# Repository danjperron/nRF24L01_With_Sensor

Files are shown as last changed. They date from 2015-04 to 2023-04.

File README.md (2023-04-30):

# nRF24L01_With_Sensor
Read DHT22, DS18B20, MAX6675, Humidity capacitive sensor via nRF24L01 transmitter with an arduino 

Arduino pin out for DHT22

  <pre>
  2   DHT22     DATA with a 4k7 pull-up resistor
  4   DHT22     POWER  I use IO pin to reduce power
  GND DHT22     GND
  3   nRF24L01  IRQ   pin 8.
  7   nRF24L01  CS    pin 4
  8   nRF24L01  CE pin 3
  11  nRF24L01  MOSI  pin 6
  12  nRF24L01  MISO  pin 7
  13  nRF24L01  SCK   pin 5
  3.3V nRF24L01 VCC   pin 2
  GND nRF24L01  GND p in 1
</pre>

N.B. Pins are specific to the sensor.

Needed library 
 - RF24 by TMRh20 from arduino library
 - Sleep_n0m1 by Noah Shibley from arduino library

Needed library for specific sensors
 <s>- http://playground.arduino.cc//Main/DHTLib</s> Check for DHTlib  in library manager
 - http://www.pjrc.com/teensy/td_libs_OneWire.html
<s>- http://milesburton.com/Dallas_Temperature_Control_Library</s>
- https://github.com/milesburton/Arduino-Temperature-Control-Library

And for nRF24Reader.py
 - https://github.com/BLavery/lib_nrf24.git
*** please add SPI clock speed in the function begin if the nRf24L01 doesn't work
    self.spidev.max_speed_hz=8000000

I made some video in French explaining the use of it in my garden
  - Part 1 https://www.youtube.com/watch?v=X7y6lOSt4_s
  - Part 2 https://www.youtube.com/watch?v=79MHdWFCXho
  - Part 3 Not done yet! Will be about humidity calibration and node red

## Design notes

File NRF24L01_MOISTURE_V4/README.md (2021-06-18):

# nRF24L01_With_Sensor
Lire humidité par un capteur capacitif 

Arduino pin out 

  <pre>
  GND Batterie, capteur  GND
  7   nRF24L01  CS    pin 4
  8   nRF24L01  CE pin 3
  11  nRF24L01  MOSI  pin 6
  12  nRF24L01  MISO  pin 7
  13  nRF24L01  SCK   pin 5
  3.3V nRF24L01 VCC   pin 2
  GND nRF24L01  GND p in 1
  9   Capteur CLOCK OUT
  A0  capteur signal
  A1  input foure-tout (pas utilis&acute; mais le systeme retourne la valeur)
</pre>

Librairie nécessaire extraite directement d'arduino 
 - RF24 de TMRh20 
 - Sleep_n0m1 de Noah Shibley 

Librairie Python pour le Raspberry Pi 

 - https://github.com/BLavery/lib_nrf24.git
   *** Il faut corriger la fonction begin pour include la vitesse d`horloge du SPI, sinon c'est trop vite.
    self.spidev.max_speed_hz=8000000
   P.S. une version corrigé du lib_nrf24.git est inclus.
 - numpy      sudo pip3 install numpy  (cela va prendre du temps).
 - mosquitto-clients   sudo pip3 install mosquitto-clients
 
 Si vous n'avez pas de serveur MQTT  vous pouvez en installer un sur le PI
   sudo apt install mosquitto

Information sur les répertoires,

- Demo1    Démo  Transférer du texte.
- Demo2    Démo  Transférer des données en packet.
- Demo3    Démo  Transférer des données en packet mais avec le capteur
           capacitif modifié avec le clock de l`arduino et aussi mettre
           le système en mode sleep.

-RF24L01_MOISTURE_V4  Version final incluant le mode du Demo3 mais en shockburst ce qui permet de synchroniser
           et d'avoir plusieur capteurs.

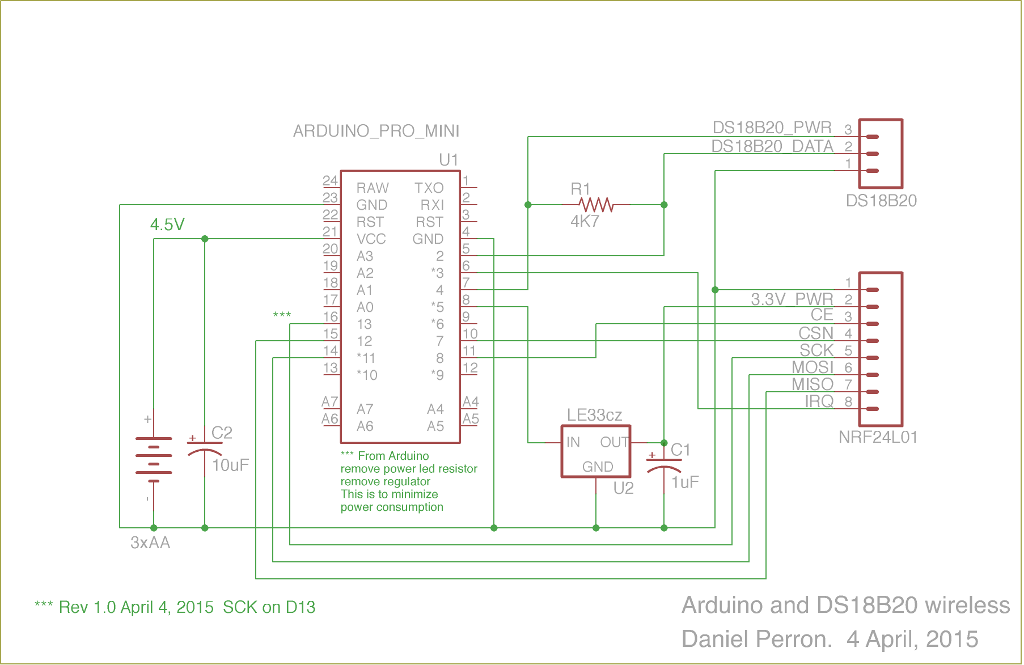
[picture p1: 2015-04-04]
nRF24L01_DS18B20.png

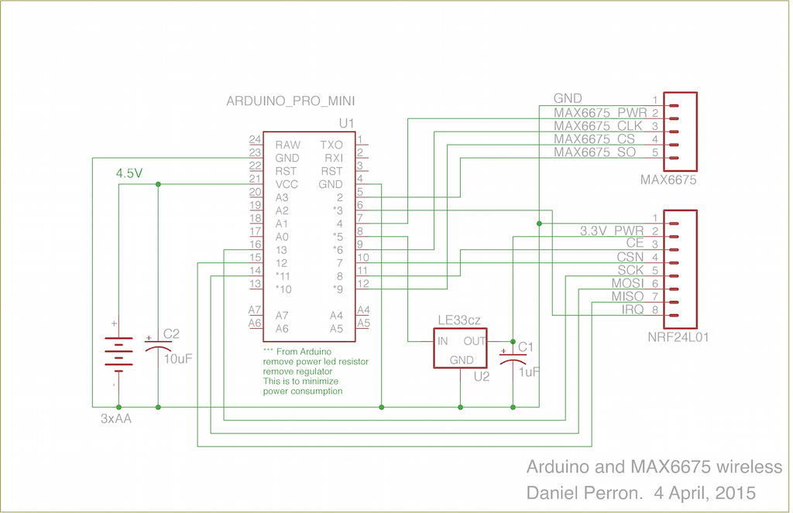
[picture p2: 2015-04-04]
nRF24L01_MAX6675.png

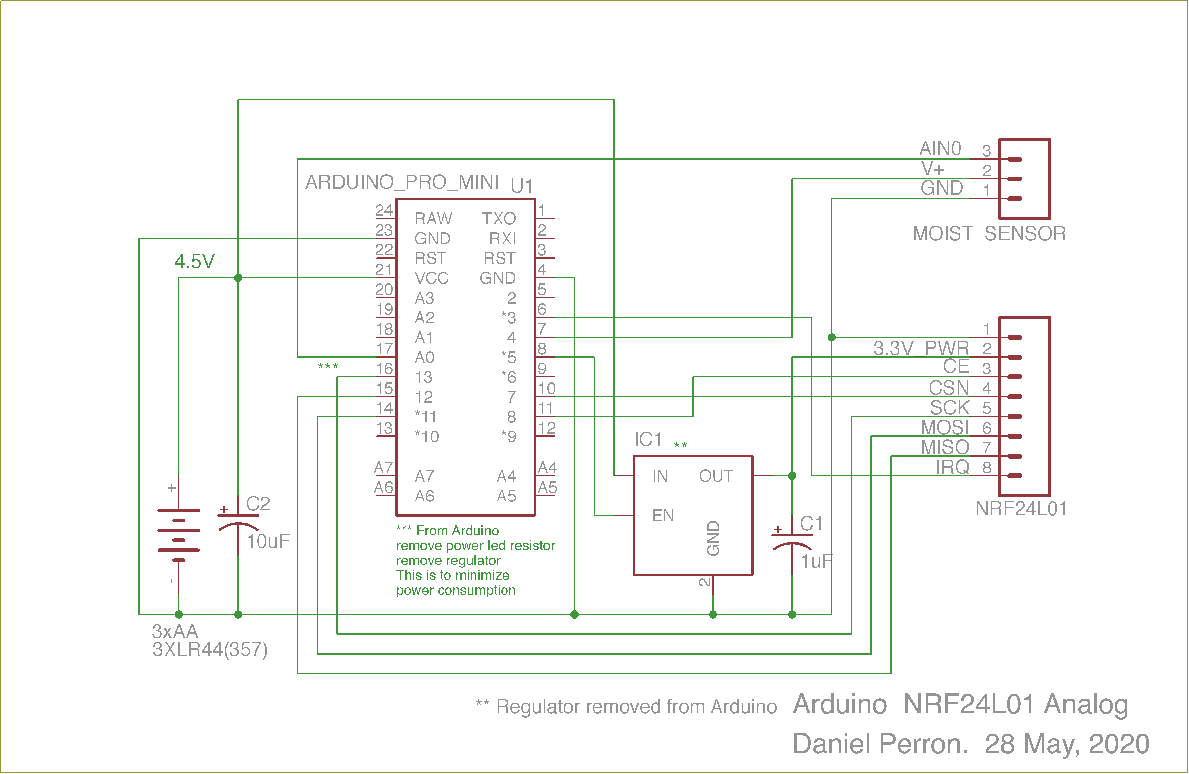
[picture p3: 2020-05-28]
AnalogBeta/nRF24L01_Analog.png

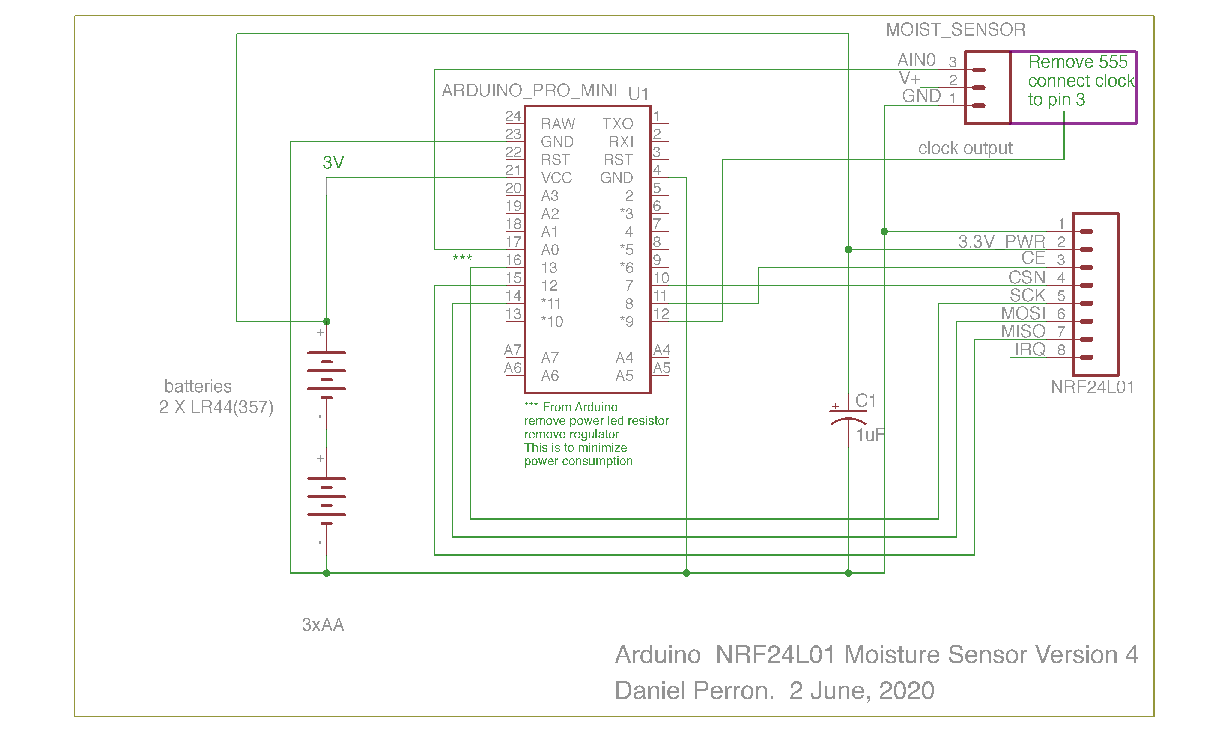
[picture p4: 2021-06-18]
NRF24L01_MOISTURE_V4/RF24L01_MOISTURE_V4.png

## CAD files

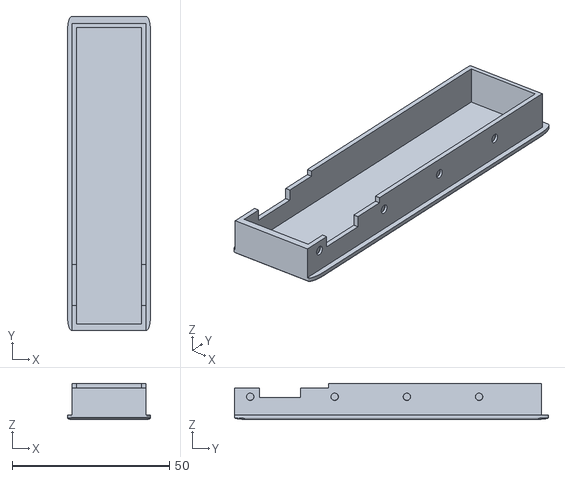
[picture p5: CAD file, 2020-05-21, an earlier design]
NRF24L01_MOISTURE_V2/moisture sensor RF top cover.stl
26.5 x 100.0 x 11.5

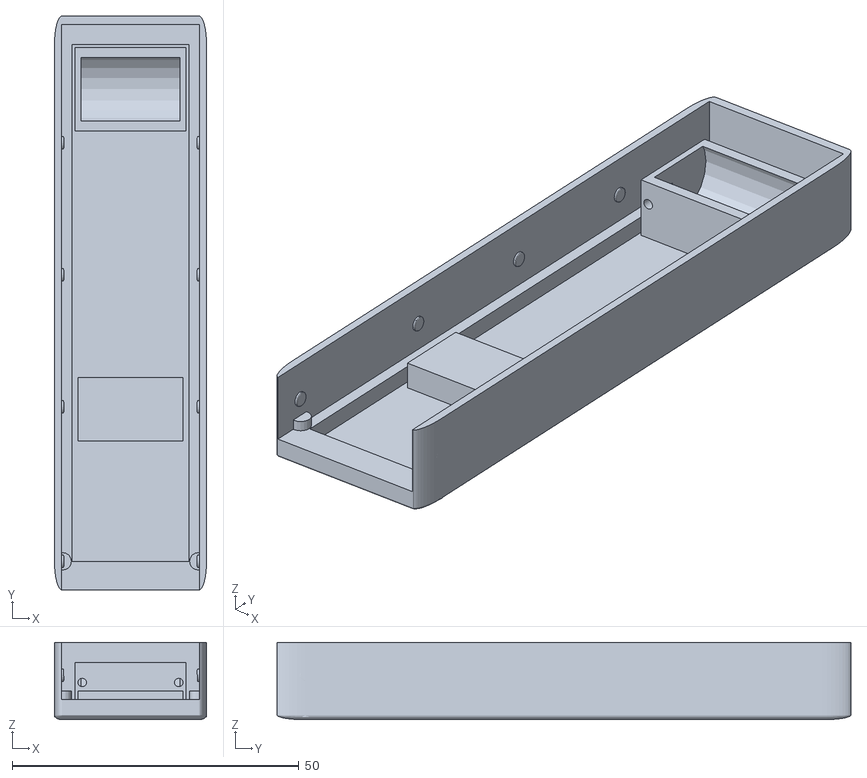
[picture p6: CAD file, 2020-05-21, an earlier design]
NRF24L01_MOISTURE_V2/moisture base cover sensor RF.stl
26.5 x 100.0 x 13.5

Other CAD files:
NRF24L01_MOISTURE_V2/moisture sensor RF box top cover.stl
NRF24L01_MOISTURE_V2/moisture sensor RF box base.stl

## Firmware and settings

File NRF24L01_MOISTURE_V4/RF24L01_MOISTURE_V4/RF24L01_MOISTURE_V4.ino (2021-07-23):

#include <nRF24L01.h>
#include <RF24_config.h>
#include <RF24.h>
#include <SPI.h>
#include <Sleep_n0m1.h>
#include "printf.h"


/*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
  Read Moisture sensor  via nRF24L01 transmitter.

  Version 4.0 June 2021 Daniel Perron

  This is a simplified version using only 3V.
 
  The capacitive sensor has the 555 timer removed and D9 clock the sensor
  
*/



/**** cycle loop behavior *****/

// NO_WAIT    the unit keep looping without doing sleep
//#define NO_WAIT 

// DISABLE_SLEEP    disable deep sleep  use delay instead
//#define DISABLE_SLEEP

#define   SERIAL_DEBUG


/***** capacitive sensor clock definition ****/

#define CLOCK_PIN  9
#define CLOCK_FREQUENCY 800000



/*******  RF24 definition                *****/

// UNIT_ID     ID number of the device for nRF24L01

#define RF24_CE_PIN  8
#define RF24_CSN_PIN 7

//#define RF24_DATA_RATE RF24_1MBPS
//#define RF24_DATA_RATE RF24_2MBPS
#define RF24_DATA_RATE RF24_250KBPS

//#define RADIO_CHANNEL 72
#define RADIO_CHANNEL 80


#define RF24_PA_LEVEL RF24_PA_MIN
//#define RF24_PA_LEVEL RF24_PA_LOW
//#define RF24_PA_LEVEL RF24_PA_HIGH


#define UNIT_ID 0x03

// Radio pipe addresses for the 2 nodes to communicate.
const uint64_t serverPipe = 0xE0E0E0E001LL;
const uint64_t sensorPipe = 0xA5A5A5A500LL | UNIT_ID;


/********   Variables   ******/
short analog0;  // analog capacitive value
short analog1;  // spare analog input
short vcc;      // value of vcc
unsigned long clockFrequency= CLOCK_FREQUENCY;

/*******  sleep mode class ******/
Sleep sleep;
unsigned long sleepTime = 300000;

/******* radio class ******/
RF24 radio(RF24_CE_PIN,RF24_CSN_PIN);

unsigned long Count = 0;

// because of sleep mode calibration problem
// and I don't want to change the library
// we will mimic the calibration
// by disable it and enable only when we reach 0 at modulus 720
// we will calibrate the watch dog  when we wait  for the DS18B20 conversion

#define        WD_CALIB_COUNT   720
unsigned short WDCalibrationCycle = 0;


void StartRadio()
{
#ifdef SERILAL_DEBUG
  Serial.print("*** START RADIO ***\n");
#endif

  radio.begin();                          // Start up the radio
  radio.setChannel(RADIO_CHANNEL);
  radio.setDataRate(RF24_DATA_RATE);
  radio.setPALevel(RF24_PA_LEVEL);
  radio.setPayloadSize(32);
  radio.setAutoAck(1);                    // Ensure autoACK is enabled
  radio.setRetries(7, 4);  // Max delay between retries & number of retries
  radio.enableDynamicPayloads();
  radio.enableAckPayload();
  radio.maskIRQ(true, true, false);
  //role = role_ping_out;                  // Become the primary transmitter (ping out)
  radio.openWritingPipe(serverPipe);
  radio.openReadingPipe(1,sensorPipe);
  radio.startListening();                 // Start listening
}


//***************  TIMER1  CLOCK OSCILLATOR ON OC1A


// clock is on D9
// this only works for frequency CPU_CLOCK/2 to CPU_CLOCK/65536
// adapted to take care of compile cpu clock (F_CPU)
void setClock(unsigned long tempfreq){
  unsigned long SquareWaveClock = (unsigned long) F_CPU /2L;
  pinMode(CLOCK_PIN, OUTPUT);
  cli();//disable interupts
  TCCR1A = 0;//registers for timer 1
  TCCR1B = 0;
  TCNT1=0;
  TCCR1A |= _BV(COM1A0);
  TCCR1B |=_BV(WGM12);
  TCCR1C = _BV(FOC1A);
  OCR1A = (SquareWaveClock/tempfreq)-1;//#TIMER COUNTS
  TCCR1B |= _BV(CS10);
  sei();//enable interupts
}



void killClock(void)
{
  cli();//disable interupts
  TCCR1A = 0;//registers for timer 1
  TCCR1B = 0;
  TCNT1=0;
  sei();
  digitalWrite(CLOCK_PIN,LOW);
}


//****************  800KHZ CLock END



void setup() {
#ifdef SERIAL_DEBUG
  Serial.begin(57600);
  printf_begin();
  printf("\n\rRF24 ANALOG\n\r");
#endif
  StartRadio();
#ifdef SERIAL_DEBUG
  radio.stopListening();
  radio.printDetails();                   // Dump the configuration of the rf unit for debugging
  radio.startListening();
#endif
  // disable calibration interval by setting modulus to
  sleep.setCalibrationInterval(1);

}


/********  cycle state definition *****/

enum cycleMode {ModeInit, ModeListen, ModeReadSensor, ModeWriteData, ModeWait};

cycleMode cycle = ModeInit;



/********  type of sensor definition *****/

#define STRUCT_TYPE_GETDATA    0
#define STRUCT_TYPE_INIT_DATA  1
#define STRUCT_TYPE_DHT22_DATA 2
#define STRUCT_TYPE_DS18B20_DATA 3
#define STRUCT_TYPE_MAX6675_DATA 4
#define STRUCT_TYPE_DIGITAL_OUTPUT 5
#define STRUCT_TYPE_ANALOG_DATA  6
#define STRUCT_TYPE_MOISTURE_DATA 7

#define STATUS_DATA_VALID  1
#define STATUS_TIME_OUT    2


/******* data structure for STRUCT_TYPE_MOISTURE_DATA ******/


typedef struct
{
  char header;
  unsigned char structSize;
  unsigned char structType;
  unsigned char txmUnitId;
  unsigned long currentTime;
  unsigned short nextTimeReading;
  unsigned short nextTimeOnTimeOut;
  unsigned long  clockFrequency;
  unsigned char  clockFrequencyValid;
  char Spare[15];
} RcvPacketStruct;


typedef struct
{
  char header;
  unsigned char structSize;
  unsigned char structType;
  unsigned char txmUnitId;
  unsigned char Status;
  unsigned long  stampTime;
  unsigned short voltageA2D;
  unsigned short analog0;
  unsigned short analog1;
  unsigned long  frequency;
} TxmMoisturePacketStruct;


unsigned long currentDelay;
unsigned long targetDelay;

RcvPacketStruct RcvData;
TxmMoisturePacketStruct Txmdata;

unsigned char * pt = (unsigned char *) &RcvData;


unsigned char rcvBuffer[32];
unsigned short nextTimeOnTimeOut = 300;
const unsigned short waitTimeOnListen = 10;
unsigned long  startTimeOnListen;

void PrintHex(uint8_t *data, uint8_t length) // prints 16-bit data in hex with leading zeroes
{
#ifdef SERIAL_DEBUG
  char tmp[32];
  for (int i = 0; i < length; i++)
  {
    sprintf(tmp, "0x%.2X", data[i]);
    Serial.print(tmp); Serial.print(" ");
  }
#endif
}



bool readSensor()
{
  // enable clock output
  if(clockFrequency < 10000)
    clockFrequency=CLOCK_FREQUENCY;
   
  setClock(clockFrequency);

  // Wait 300 ms
  delay(300);

  //ok read sensor and nRF24L01 batteries
  analog0 = analogRead(A0);
  analog1 = analogRead(A1);
  vcc     = readVcc();


#ifdef SERIAL_DEBUG
  Serial.println("Get data");
  Serial.print("Moisture:");
  Serial.println(analog0);
  Serial.print("Two batteries:");
  Serial.println(analog1);
  Serial.print("Frequency:");
  Serial.println(clockFrequency);
  Serial.print("VCC:");
  Serial.println(vcc);
#endif

  // kill clock
  killClock();
  return (1);
}





//From http://provideyourown.com/2012/secret-arduino-voltmeter-measure-battery-voltage/
unsigned short readVcc() {
  // Read 1.1V reference against AVcc
  // set the reference to Vcc and the measurement to the internal 1.1V reference
#if defined(__AVR_ATmega32U4__) || defined(__AVR_ATmega1280__) || defined(__AVR_ATmega2560__)
  ADMUX = _BV(REFS0) | _BV(MUX4) | _BV(MUX3) | _BV(MUX2) | _BV(MUX1);
#elif defined (__AVR_ATtiny24__) || defined(__AVR_ATtiny44__) || defined(__AVR_ATtiny84__)
  ADMUX = _BV(MUX5) | _BV(MUX0);
#elif defined (__AVR_ATtiny25__) || defined(__AVR_ATtiny45__) || defined(__AVR_ATtiny85__)
  ADMUX = _BV(MUX3) | _BV(MUX2);
#else
  ADMUX = _BV(REFS0) | _BV(MUX3) | _BV(MUX2) | _BV(MUX1);
#endif

  delay(5); // Wait for Vref to settle
  ADCSRA |= _BV(ADSC); // Start conversion
  while (bit_is_set(ADCSRA, ADSC)); // measuring

  uint8_t low  = ADCL; // must read ADCL first - it then locks ADCH
  uint8_t high = ADCH; // unlocks both

  long result = (high << 8) | low;

#define VOLTAGE_FACTOR 1125300L
//#define VOLTAGE_FACTOR   1186125L
  result = VOLTAGE_FACTOR / result; // Calculate Vcc (in mV); 1125300 = 1.1*1023*1000
  return (unsigned short) result; // Vcc in millivolts
}


void loop(void) {
  int loop;
  unsigned long deltaTime;
  /****************** Ping Out Role ***************************/

  if (cycle == ModeInit)
  {
    Count++;
    Txmdata.header = '*';
    Txmdata.structSize = sizeof(TxmMoisturePacketStruct);
    Txmdata.structType = STRUCT_TYPE_INIT_DATA;
    Txmdata.txmUnitId = UNIT_ID;
    Txmdata.stampTime = 0;
    Txmdata.Status = 0;
    Txmdata.analog0 = 0;
    Txmdata.analog1 = 0;
    Txmdata.frequency = 0;
    Txmdata.voltageA2D = readVcc();
    radio.writeAckPayload(1, &Txmdata, sizeof(TxmMoisturePacketStruct));
    cycle = ModeListen;
    startTimeOnListen = millis();
  }

  if (cycle == ModeListen)
  {
    if (radio.available())
    {
      int rcv_size = radio.getDynamicPayloadSize();
      radio.read( &RcvData, rcv_size);

      if (RcvData.header != '*')
      {
        cycle = ModeWriteData;
        return;
      }

      if(RcvData.clockFrequencyValid)
         clockFrequency=RcvData.clockFrequency;

#ifdef SERIAL_DEBUG
      Serial.print("Received after ");
      Serial.print((millis() - startTimeOnListen) / 1000.0);
      Serial.print(" sec\n");
      Serial.print("T:" );
      Serial.print(RcvData.currentTime);
      Serial.print(" Next reading in (1/10 sec): ");
      Serial.print(RcvData.nextTimeReading);
      Serial.print("\n");
      PrintHex(pt, rcv_size);
      Serial.print("\n");
#endif
      currentDelay = millis();
#ifdef DISABLE_SLEEP
      delay(200);
#endif


      nextTimeOnTimeOut = RcvData.nextTimeOnTimeOut;

      if (RcvData.nextTimeReading > 20)
      {
        sleepTime =  (unsigned long) RcvData.nextTimeReading * 100 ;
#ifdef SERIAL_DEBUG
        Serial.print("New sleeptime (ms) =");
        Serial.println(sleepTime);
#endif        
        cycle = ModeWait;
      }
      else
        cycle = ModeReadSensor;
    }
    else
    {

      deltaTime = (millis() - startTimeOnListen) / 1000;
      // did we have time out
      if (deltaTime > waitTimeOnListen)
      {
        // ok we got time out
#ifdef SERIAL_DEBUG
        Serial.print("got time out!");
        Serial.print(deltaTime);
        Serial.print("sec.  Sleep for ");
        Serial.print(nextTimeOnTimeOut);
        Serial.print("sec.\n");
#endif
       
        sleepTime = (unsigned long) nextTimeOnTimeOut * 1000;
        cycle = ModeWait;

      }
    }

  }


  if (cycle == ModeWait)
  {
    radio.powerDown();
    delay(5);
    SPI.end();
#ifndef NO_WAIT    
#ifdef DISABLE_SLEEP
    delay(sleepTime);
#else
#ifdef SERIAL_DEBUG
    Serial.print("Go to Sleep ");
    Serial.print(sleepTime);
    Serial.println("ms");
    delay(100);
#endif
    sleep.pwrDownMode();
    sleep.sleepDelay(sleepTime);
#endif

#ifdef SERIAL_DEBUG
    Serial.println("Arduino WakeUP");
#endif
    
#endif
    radio.powerUp();
    cycle = ModeReadSensor;
  }

  if (cycle == ModeReadSensor)
  {
    if (readSensor())
    {
      Txmdata.analog0 = analog0;
      Txmdata.analog1 = analog1;
      Txmdata.voltageA2D = vcc;
      Txmdata.frequency = clockFrequency;
      Txmdata.Status = STATUS_DATA_VALID;
    }
    cycle = ModeWriteData;
  }

  if (cycle == ModeWriteData)
  {
    Txmdata.stampTime = RcvData.currentTime;
    Txmdata.header = '*';
    Txmdata.structSize = sizeof(TxmMoisturePacketStruct);
    Txmdata.structType = STRUCT_TYPE_MOISTURE_DATA;
    Txmdata.txmUnitId = UNIT_ID;
    Txmdata.stampTime = RcvData.currentTime + (deltaTime / 1000);
    StartRadio();
    radio.writeAckPayload(1, &Txmdata, sizeof(TxmMoisturePacketStruct));
    startTimeOnListen = millis();
    cycle = ModeListen;
  }

}

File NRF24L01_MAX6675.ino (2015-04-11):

/*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
 Read max6675 sensor using a nRF24L01 sensor base on J.Coliz code
 
*/



/*
 Copyright (C) 2011 J. Coliz <maniacbug@ymail.com>

 This program is free software; you can redistribute it and/or
 modify it under the terms of the GNU General Public License
 version 2 as published by the Free Software Foundation.
//2014 - TMRh20 - Updated along with Optimized RF24 Library fork
 */

/**
 * Example for Getting Started with nRF24L01+ radios. 
 *
 * This is an example of how to use the RF24 class to communicate on a basic level.  Write this sketch to two 
 * different nodes.  Put one of the nodes into 'transmit' mode by connecting with the serial monitor and
 * sending a 'T'.  The ping node sends the current time to the pong node, which responds by sending the value
 * back.  The ping node can then see how long the whole cycle took. 
 * Note: For a more efficient call-response scenario see the GettingStarted_CallResponse.ino example.
 * Note: When switching between sketches, the radio may need to be powered down to clear settings that are not "un-set" otherwise
 */


#include <SPI.h>
#include <Sleep_n0m1.h>
#include "nRF24L01.h"
#include "RF24.h"
#include "printf.h"



#define MAX_SO_PIN  2
#define MAX_CLK_PIN 6
#define MAX_CS_PIN  9

#define MAX_POWER_PIN 4

#define RF24_POWER_PIN 5



//assuming one sensor per device
// we will use the SKIP command


float celsius;

Sleep sleep;

unsigned long sleepTime=300000;

short  temperature= 32767;


// energy mode

//#define DISABLE_SLEEP

///////////////   radio /////////////////////
// Hardware configuration: Set up nRF24L01 radio on SPI bus plus pins 9 & 10 
RF24 radio(8,7);

#define UNIT_ID 0xc5

const uint8_t MasterPipe[6] = {0xe7,0xe7,0xe7,0xe7,0xe7,0};

const uint8_t SensorPipe[6]  = { UNIT_ID,0xc2,0xc2,0xc2,0xc2,0};


// Radio pipe addresses for the 2 nodes to communicate.


// Set up roles to simplify testing 
//boolean role;                                    // The main role variable, holds the current role identifier
//boolean role_ping_out = 1, role_pong_back = 0;   // The two different roles.
unsigned long Count=0;


void StopRadio()
{
  pinMode(RF24_POWER_PIN,OUTPUT);
  digitalWrite(RF24_POWER_PIN,LOW);
}


void StartRadio()
{
  pinMode(RF24_POWER_PIN,OUTPUT);
  digitalWrite(RF24_POWER_PIN,HIGH);
  delay(50);  
  radio.begin();                          // Start up the radio
  radio.setPayloadSize(32);
  radio.setChannel(0x4e);
  radio.setDataRate(RF24_1MBPS);
  radio.setAutoAck(1);                    // Ensure autoACK is enabled
  radio.setRetries(7,3);   // Max delay between retries & number of retries
  radio.enableDynamicPayloads();
  radio.enableAckPayload();
  radio.maskIRQ(true,true,false);
  //role = role_ping_out;                  // Become the primary transmitter (ping out)
  radio.openWritingPipe(MasterPipe);
  radio.openReadingPipe(1,SensorPipe);
  radio.startListening();                 // Start listening
}



void setup() {
  // Set pin for DHT22 power
  StopSensor();
  
  Serial.begin(57600);
  printf_begin();
  printf("\n\rRF24/examples/GettingStarted/\n\r");
  printf("*** PRESS 'T' to begin transmitting to the other node\n\r");

  StartRadio();
  radio.stopListening();
  radio.printDetails();                   // Dump the configuration of the rf unit for debugging
  radio.startListening();
}





enum cycleMode {ModeInit,ModeListen,ModeWriteData,ModeWait};

cycleMode cycle= ModeInit;


#define STRUCT_TYPE_GETDATA    0
#define STRUCT_TYPE_INIT_DATA  1
#define STRUCT_TYPE_DHT22_DATA 2
#define STRUCT_TYPE_DS18B20_DATA 3
#define STRUCT_TYPE_MAX6675_DATA    4


#define STATUS_DATA_VALID 1
#define STATUS_TIME_OUT   2

typedef struct
{
  char header;
  unsigned char structSize;
  unsigned char structType;
  unsigned char txmUnitId;
  unsigned long currentTime;
  unsigned short nextTimeReading;
  unsigned short nextTimeOnTimeOut;
  char Spare[20];
}RcvPacketStruct;


typedef struct
{
   char header;
   unsigned char structSize;
   unsigned char structType;
   unsigned char txmUnitId;
   unsigned char Status;
   unsigned long  stampTime;
   unsigned short voltageA2D;
   unsigned short temperature;
}TxmMAX6675PacketStruct;


unsigned long currentDelay;
unsigned long targetDelay;

RcvPacketStruct RcvData;
TxmMAX6675PacketStruct Txmdata;

unsigned char * pt = (unsigned char *) &RcvData;


unsigned char rcvBuffer[32];
unsigned short nextTimeOnTimeOut = 60;
unsigned short waitTimeOnListen = 60;
unsigned long startTimeOnListen;
unsigned char gotTimeOut=0;


void PrintHex(uint8_t *data, uint8_t length) // prints 16-bit data in hex with leading zeroes
{
       char tmp[32];
       for (int i=0; i<length; i++)
       { 
         sprintf(tmp, "0x%.2X",data[i]); 
         Serial.print(tmp); Serial.print(" ");
       }
}



void StopSensor(void)
{
  pinMode(MAX_POWER_PIN, OUTPUT);
  digitalWrite(MAX_POWER_PIN, LOW);
  pinMode(MAX_CS_PIN,OUTPUT);
  digitalWrite(MAX_CS_PIN,LOW);
  pinMode(MAX_CLK_PIN,OUTPUT);
  digitalWrite(MAX_CLK_PIN,LOW);
  pinMode(MAX_SO_PIN,INPUT);
}

void PowerSensor(void)
{
  pinMode(MAX_POWER_PIN, OUTPUT);
  digitalWrite(MAX_POWER_PIN, HIGH);
  pinMode(MAX_CS_PIN,OUTPUT);
  digitalWrite(MAX_CS_PIN,HIGH);
  pinMode(MAX_CLK_PIN,OUTPUT);
  digitalWrite(MAX_CLK_PIN,LOW);
  pinMode(MAX_SO_PIN,INPUT_PULLUP);
}  
  
  
  


bool readSensor(void)
{
  word data=0;
  int loop;
  
  //CS LOW
  digitalWrite(MAX_CS_PIN,LOW);
  
  for(loop=0;loop<16;loop++)
  {
    // clock up
    digitalWrite(MAX_CLK_PIN,HIGH);
    data <<=1;
    if(digitalRead(MAX_SO_PIN))
        data |=1;
    digitalWrite(MAX_CLK_PIN,LOW);        
  }
  
  // CS HIGH
  digitalWrite(MAX_CS_PIN,HIGH);  
  
    if((data & 2) == 2)
       {
           Serial.println("Sensor Error");
           return 0;
       }
           
    if((data & 4) == 4)
       {
           Serial.println("Probe error");
           return 0;
       }
       
     data >>=3;
     temperature= data;
     celsius = data /4.0;
     Serial.print("temperature :");
     Serial.println(celsius);
 
     return 1;
}
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

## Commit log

2015-03-25 reduce DHT22 current on sleep
2015-04-02 add DS18B20 schematic
2015-04-04 fix schematic
2015-04-04 add max6675 schematic
2015-04-05 add max6675 sensor
2015-04-06 update python to minimize sensor transmitter ON time
2015-04-11 increase power reduction
2015-04-11 fix probe.timeOut
2015-04-14 Change Watch dog calibration cycle
2020-05-15 Add analog prototype
2020-05-15 analog MQTT are in Volt
2020-05-20 Add STL files
    [moisture sensor RF box base.stl, moisture sensor RF box top cover.stl]
2020-05-21 modified STL for V 1.2
    [moisture base cover sensor RF.stl, moisture sensor RF top cover.stl]
2020-05-28 add schematic for analog moisture sensor
2020-06-02 add Moisture Version 2.0
    [moisture base cover sensor RF.stl, moisture sensor RF box base.stl, moisture sensor RF box top cover.stl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]
2020-06-04 remove frequency print out on python code

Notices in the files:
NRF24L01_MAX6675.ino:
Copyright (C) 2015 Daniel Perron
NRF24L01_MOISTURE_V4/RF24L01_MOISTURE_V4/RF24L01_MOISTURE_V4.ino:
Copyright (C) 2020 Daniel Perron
